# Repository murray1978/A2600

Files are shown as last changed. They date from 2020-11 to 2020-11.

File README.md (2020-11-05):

# A2600
Atari 2600 clone/portable using period correct 6507, RIOT(6532) and a TIA(NTSC version).

## Changes to the original
- Removed the Audio subcarrier generator
- Removed the RF modulator

- Added a 74LS04 Clock generator
- Added RCA Video and Audio output

## Current Schematic
The current schematic references the Rev 14 and 15 schematics from the Feild Service Manual FD100133 Rev 02

## Current Board
Currently the board uses through hole components, in order to shrink the board even more I could go to a surface mount approach.
Pre fabrication check List, 
1. [ ] All gronds on ground plane connected
2. [ ] headers around the right way
3. [ ] VCC connected to components
4. [ ] correct footprints 
5. [ ] dont belive DRC in kicad

## Where to get parts

## Construction

## Trouble shooting

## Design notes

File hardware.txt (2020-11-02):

2600 cartridge pinouts
A standard 2600 cartridge contains the equivalent of a 2716 or 2732/2532 with one notable exception: the chip select line is active high, not low. The high order address line of the 6507 (A12) is used as the chip enable. There was at least one company that used EPROMs with a 74LS04 inverter to compensate for this. Note that numbers indicate left to right numbering.

        Top Row                 Bottom Row
Slot    2716    CPU             2716    CPU

1       13      D3              1       A7
2       14      D4              2       A6
3       15      D5              3       A5
4       16      D6              4       A4
5       17      D7              5       A3
6       *       A12             6       A2
7       19      A10             7       A1
8       NC      A11             8       A0
9       22      A9              9       D0
10      23      A8              10      D1
11      24      +5V             11      D2
12      12      Shield Ground   NC      Ground
    * to inverter and back to 18 for chip select

(Looking at the bottom of the cartridge -- i.e. edge connectors first)
                        Top
 D3   D4   D5   D6   D7   A12  A10  A11  A9   A8  +5V   SGND
--1- --2- --3- --4- --5- --6- --7- --8- --9- -10- -11- -12-
 GND  D2   D1   D0   A0   A1   A2   A3   A4   A5   A6   A7
                        Bottom

Dx = Data line x
Ax = Address line x
+5V = +5 volts
SGND = Shield Ground
GND = Ground
Notes:

On both cartridges that were opened, GND was also connected to SGND. Best to make sure that they are wired together.
A11 and A12 could be switched. On both the chips I've checked, A12 was hardwired to +5 volts which leads me to believe that it is the highest address line. Since I believe that these chips are only 4Kx8 ROMs, this seems logical, since A12 would actually be just the chip enable for ROM (right?). Only the 2600 info tells differently, and it doesn't give any connection for A11 on the EPROM, so I don't trust it. Unfortunately, since the 2716 EPROM is used as an example, we won't know without actually trying one, since the 2716 doesn't really use A11 or A12 and either one could be used as a chip enable.
Address
lines           Memory
used            Available       EPROM   Memory
======================================================
A11             2048            2716    2K
A12             4096            2732    4K
A13             8192            2764    8K  (needs support chips for banking)
A13             8192        2 x 2732    8K  (most common of 8K config)

    ____________
    |   2716   |
A7  | 1     24 | VCC [+5 V]
A6  | 2     23 | A8
A5  | 3     22 | A9
A4  | 4     21 | VPP [Doesn't matter probably.  +5V]
A3  | 5     20 | !Output Enable (always on) [GND]
A2  | 6     19 | A10
A1  | 7     18 | !Chip Enable (make high bit) [inverted A12]
A0  | 8     17 | D7
D0  | 9     16 | D6
D1  | 10    15 | D5
D2  | 11    14 | D4
GND | 12    13 | D3
    |__________|
    ____________
    |   2732   |
A7  | 1     24 | VCC [+5 V]
A6  | 2     23 | A8
A5  | 3     22 | A9
A4  | 4     21 | A11
A3  | 5     20 | !Output Enable (always on) [GND] / VPP
A2  | 6     19 | A10
A1  | 7     18 | !Chip Enable (make high bit) [inverted A12]
A0  | 8     17 | D7
D0  | 9     16 | D6
D1  | 10    15 | D5
D2  | 11    14 | D4
GND | 12    13 | D3
    |__________|
    ____________
    |   2764   |
VPP | 1     28 | VCC [+5 V]
A12 | 2     27 | !Program Strobe (no connection?) [+5V]
A7  | 3     26 | No Connection
A6  | 4     25 | A8
A5  | 5     24 | A9
A4  | 6     23 | A11
A3  | 7     22 | !Output Enable (always on) [GND]
A2  | 8     21 | A10
A1  | 9     20 | !Chip Enable (always on) [GND]
A0  | 10    19 | D7
D0  | 11    18 | D6
D1  | 12    17 | D5
D2  | 13    16 | D4
GND | 14    15 | D3
    |__________|

VPP was also set at +5V for the 2764.

Q: How do I build a video driver for the 2600?
A: Parts list:

T1 2SC1815
R1 2.7K
R2 150
R3 68
L1 180 uH
L2 2.7 uH
C1, C2 100 uF 6.3 V
wire list:

R1:1 to Ground
R1:2 to Video In
R2:1 to Video In
R2:2 to T1 base
R3:1 to Ground
R3:2 to T1 emitter
L1:1 to +5V
L1:2 to T1 collector
C1:1 to Ground
C1:2 to T1 collector (positive lead of C1)
C2:1 to L2:1
C2:2 to T1 emitter (positive lead of C2)
L2:1 to C1:1
L2:2 to Video Out
                                  +5 Volts
                                     |
                                     (
                                  L1 (
                                     (
                                     |
                        R2      |/---+---+
   Video In -------+---^^^------| T1     |     + C2      L2
                   |            |\       |
                   |              >>-+---|-------| |----nnn----  Video Out
                   >                 |   |
                R1 >                 >   _ +
                   >              R3 >   - C1
                   |                 >   |
                   |                 |   |
                   +-----------------+---+--- Ground
This is a simple common emitter amplifier. It is a non-inverting current amplifier and serves here to allow the video signal from the game to drive a standard composite monitor with 75 ohm impedance.

In order to prevent the audio from interfering with the video signal, the mixing oscillator must be disabled on the main circuit board. On a 7800, remove the base lead of Q1. It is located near the RF modulator.

The audio doesn't need any extra buffering.

Places to get signals:

1. from RF modulator
   pin 3 is video
   pin 1 is ground
2. from Expansion Interface on 7800
   pin 1 is ground
   pin 2 is +5V
   pin 3 is video
   pin 17 is audio  [note: this is wrong.  Both Ben Jirou and Mark Graybill
                     agree that one cannot get audio from the expansion
                     interface.]
3. from main circuit board
on a 7800, video and ground are across C7; +5V and audio are across C4
This circuit may not work or be required with all versions of the 2600. It is required for the 7800 and the Sears Video Arcade II version of the 2600. It is probably not necessary for a 5200.

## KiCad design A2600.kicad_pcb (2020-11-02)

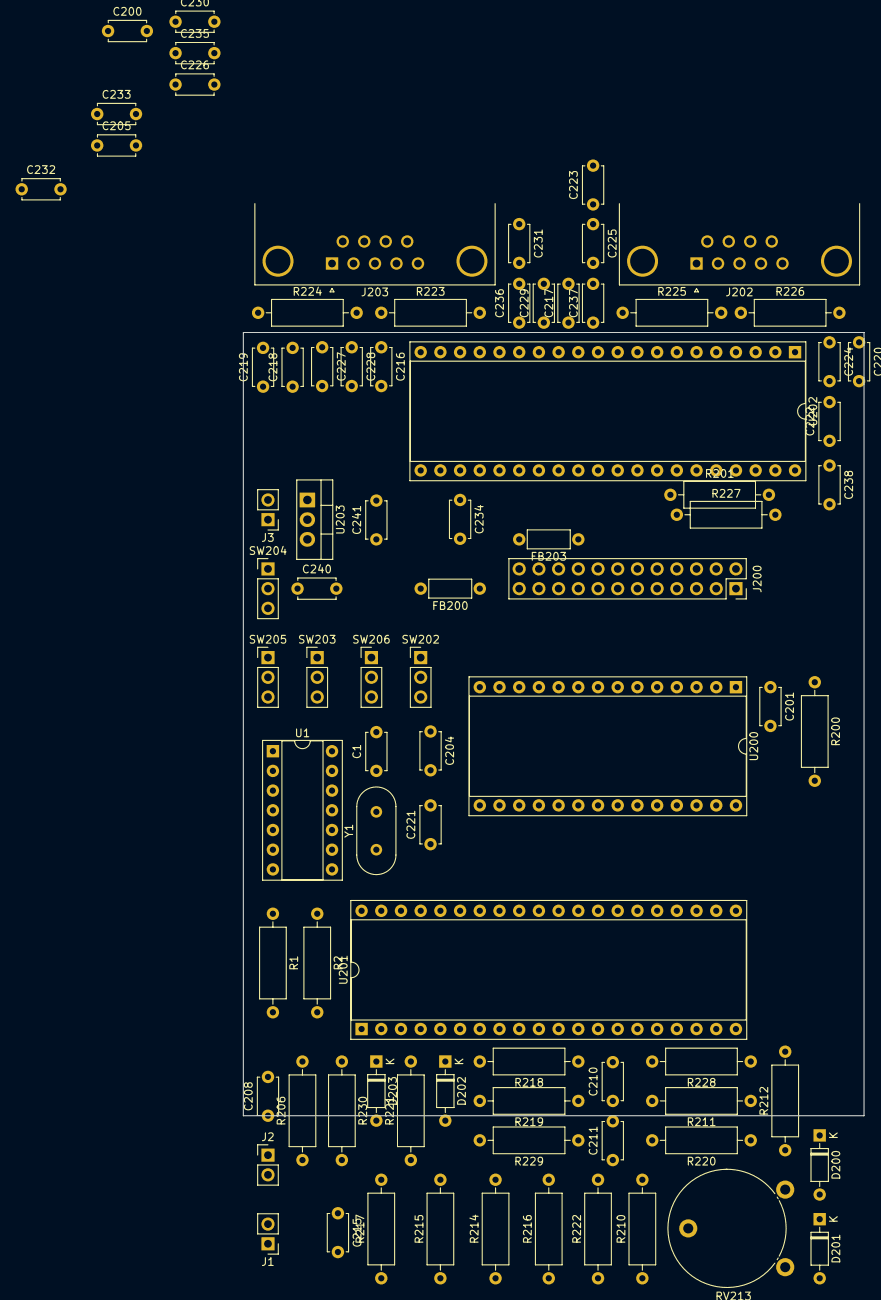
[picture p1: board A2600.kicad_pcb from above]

Board: 2 copper layers, 80.0 x 101.0 mm, 83 parts (0 on the bottom side), 72 nets, no tracks yet.

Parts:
C1: 100p; C_Disc_D4.7mm_W2.5mm_P5.00mm
C200, C205, C208, C222, C236, C237, C238, C240: 100n; C_Disc_D4.7mm_W2.5mm_P5.00mm
C201: 4u7; C_Disc_D4.7mm_W2.5mm_P5.00mm
C204: 22n; C_Disc_D4.7mm_W2.5mm_P5.00mm
C210: 47p; C_Disc_D4.7mm_W2.5mm_P5.00mm
C211: 22p; C_Disc_D4.7mm_W2.5mm_P5.00mm
C215: 150p; C_Disc_D4.7mm_W2.5mm_P5.00mm
C216, C217: 470p; C_Disc_D4.7mm_W2.5mm_P5.00mm
C218, C219, C220, C221: 68p; C_Disc_D4.7mm_W2.5mm_P5.00mm
C223, C224, C225, C226, C227, C228, C229, C230: 1p; C_Disc_D4.7mm_W2.5mm_P5.00mm
C231, C232, C233, C234, C235: 1n; C_Disc_D4.7mm_W2.5mm_P5.00mm
C241: 1u; C_Disc_D4.7mm_W2.5mm_P5.00mm
D200, D201, D202, D203: 1N914; D_DO-35_SOD27_P7.62mm_Horizontal
FB200, FB203: Ferrite_Bead; L_Axial_L5.3mm_D2.2mm_P7.62mm_Horizontal_Vishay_IM-1
J1: VIDEO; PinHeader_1x02_P2.54mm_Vertical
J2: AUDIO; PinHeader_1x02_P2.54mm_Vertical
J3: 9V; PinHeader_1x02_P2.54mm_Vertical
J200: Cartridge; PinSocket_2x12_P2.54mm_Vertical
J202: Paddle_One; DSUB-9_Female_Horizontal_P2.77x2.84mm_EdgePinOffset4.94mm_H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
J203: Paddle_Two; DSUB-9_Female_Horizontal_P2.77x2.84mm_EdgePinOffset4.94mm_H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
R1, R2, R206, R211, R228: 1K; R_Axial_DIN0309_L9.0mm_D3.2mm_P12.70mm_Horizontal
R200, R217, R227: 24K; R_Axial_DIN0309_L9.0mm_D3.2mm_P12.70mm_Horizontal
R201, R212, R219, R221: 4K7; R_Axial_DIN0309_L9.0mm_D3.2mm_P12.70mm_Horizontal
R210: 6k8; R_Axial_DIN0309_L9.0mm_D3.2mm_P12.70mm_Horizontal
R214: 27K; R_Axial_DIN0309_L9.0mm_D3.2mm_P12.70mm_Horizontal
R215: 47K; R_Axial_DIN0309_L9.0mm_D3.2mm_P12.70mm_Horizontal
R216: 110K; R_Axial_DIN0309_L9.0mm_D3.2mm_P12.70mm_Horizontal
R218, R220: 3K3; R_Axial_DIN0309_L9.0mm_D3.2mm_P12.70mm_Horizontal
R222: 15K; R_Axial_DIN0309_L9.0mm_D3.2mm_P12.70mm_Horizontal
R223, R229, R230: 10K; R_Axial_DIN0309_L9.0mm_D3.2mm_P12.70mm_Horizontal
R224, R225: 220R; R_Axial_DIN0309_L9.0mm_D3.2mm_P12.70mm_Horizontal
R226: 10k; R_Axial_DIN0309_L9.0mm_D3.2mm_P12.70mm_Horizontal
RV213: 500K; Potentiometer_Piher_PT-15-V02_Vertical
SW202: RESET; PinHeader_1x03_P2.54mm_Vertical
SW203: SELECT; PinHeader_1x03_P2.54mm_Vertical
SW204: B/W; PinHeader_1x03_P2.54mm_Vertical
SW205: Left Dif; PinHeader_1x03_P2.54mm_Vertical
SW206: RIGHT Dif; PinHeader_1x03_P2.54mm_Vertical
U1: 74LS04; DIP-14_W7.62mm_Socket
U200: R6507; DIP-28_W15.24mm_Socket
U201: TIA; DIP-40_W15.24mm_Socket
U202: 6532; DIP-40_W15.24mm_Socket
U203: L7805; TO-220-3_Vertical
Y1: 3.59545Mhz; Crystal_HC49-U_Vertical

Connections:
+9V: C241.2, J3.2, R212.2, U203.1
/A0: J200.8, U200.5, U201.32, U202.7
/A1: J200.7, U200.6, U201.31, U202.6
/A2: J200.6, U200.7, U201.30, U202.5
/A3: J200.5, U200.8, U201.29, U202.4
/A4: J200.4, U200.9, U201.27, U201.28, U202.2, U202.3
/A5: J200.3, U200.10
/A6: J200.2, U200.11, U202.40
/A7: J200.1, U200.12, U201.21, U202.38
/A8: J200.22, U200.13
/A9: J200.21, U200.14, U202.36
/A10: J200.19, U200.15
/A11: J200.20, U200.16
/A12: J200.18, U200.17, U201.24, U202.37
/D0: J200.9, U200.25, U201.14, U202.33
/D1: J200.10, U200.24, U201.15, U202.32
/D2: J200.11, U200.23, U201.16, U202.31
/D3: J200.13, U200.22, U201.17, U202.30
/D4: J200.14, U200.21, U201.18, U202.29
/D5: J200.15, U200.20, U201.19, U202.28
/D6: J200.16, U200.19, U201.33, U202.27
/D7: J200.17, U200.18, U201.34, U202.26
/PA0: C223.1, J202.1, U202.8
/PA1: C224.1, J202.2, U202.9
/PA2: C225.1, J202.3, U202.10
/PA3: C226.1, J202.4, U202.11
/PA4: C227.1, J203.1, U202.12
/PA5: C228.1, J203.2, U202.13
/PA6: C229.1, J203.3, U202.14
/PA7: C230.1, J203.4, U202.15
AnalogP1: R225.2, R226.1, U201.35
AnalogP2: R223.1, R224.2, U201.36
CADJ: C205.2, RV213.2, U201.10
GND: C200.2, C201.2, C204.2, C205.1, C215.1, C216.2, C217.2, C218.1, C218.2, C219.2, C220.2, C221.2, C222.2, C223.2, C224.2, C225.2, C226.2, C227.2, C228.2, C229.2, C230.2, C231.2, C232.2, C233.2, C234.2, C235.2, C236.2, C237.2, C238.2, C240.1, C241.1, FB203.2, J1.2, J2.2, J3.1, J200.24, J202.8, J203.5, J203.8, R222.2, RV213.1, SW202.2, SW203.2, SW204.2, SW205.2, SW206.2, U1.7, U200.2, U201.1, U201.22, U201.40, U202.1, U203.2
unnamed: C1.1, R1.1, U1.13
unnamed: C1.2, R2.2, U1.10
unnamed: C201.1, R200.1, U200.1
unnamed: C208.1, J2.1
unnamed: C208.2, R206.1, U201.12, U201.13
unnamed: C210.1, C211.2, R211.2
unnamed: C210.2, R228.2, U201.9
unnamed: C211.1, R210.2
unnamed: C215.2, J1.1, R210.1, R214.1, R215.1, R216.1, R217.1, R222.1
unnamed: C216.1, J203.6, R224.1
unnamed: C217.1, J202.6, R225.1
unnamed: C219.1, J203.9, U201.39
unnamed: C220.1, J202.5, U201.38
unnamed: C221.1, J202.9, U201.37
unnamed: C231.1, SW206.1, U202.16
unnamed: C232.1, SW205.1, U202.17
unnamed: C233.1, SW204.1, U202.21
unnamed: C234.1, SW202.1, U202.23
unnamed: C235.1, SW203.1, U202.24
unnamed: C238.1, R227.1, U202.34
unnamed: D200.2, D201.1
unnamed: D201.2, R212.1, RV213.3
unnamed: D202.1, R219.2, U201.5
unnamed: D202.2, R215.2, R229.2
unnamed: D203.1, R221.2, U201.2
unnamed: D203.2, R217.2, R230.2
unnamed: FB200.2, J200.23
unnamed: FB203.1, J200.12
unnamed: R1.2, U1.9, U1.12, Y1.1
unnamed: R2.1, U1.11, Y1.2
unnamed: R201.1, U200.3, U201.3
unnamed: R214.2, R218.2, U201.7
unnamed: R216.2, R220.2, U201.8
unnamed: U200.26, U201.25, U202.35
unnamed: U200.27, U201.4
unnamed: U200.28, U201.26, U202.39
OSC: U1.8, U201.11
VCC: C200.1, C204.1, C222.1, C236.1, C237.1, C240.2, D200.1, FB200.1, J202.7, J203.7, R200.2, R201.2, R206.2, R211.1, R218.1, R219.1, R220.1, R221.1, R223.2, R226.2, R227.2, R228.1, R229.1, R230.1, U1.14, U200.4, U201.20, U201.23, U202.20, U203.3
